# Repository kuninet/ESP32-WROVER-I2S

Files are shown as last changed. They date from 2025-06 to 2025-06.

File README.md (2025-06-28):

# ESP32-WROVER + I2S DACを使ったAirPlay、Bluetooth再生基板

## 概要

* ESP32-WROVER + I2S DACを使ったAirPlay、Bluetooth再生基板です。
* ファームウェアは、[squeezelite-esp32](https://github.com/sle118/squeezelite-esp32)を使用させていただきます。
  * https://github.com/sle118/squeezelite-esp32
* ファームウェアの書き込みには、ESP32 Downloader kitや、拙作[ESP32-Downloader](https://github.com/kuninet/ESP32-Downloader)をご使用ください。

## ☆現在 プリント基板を試作して確認中です。★

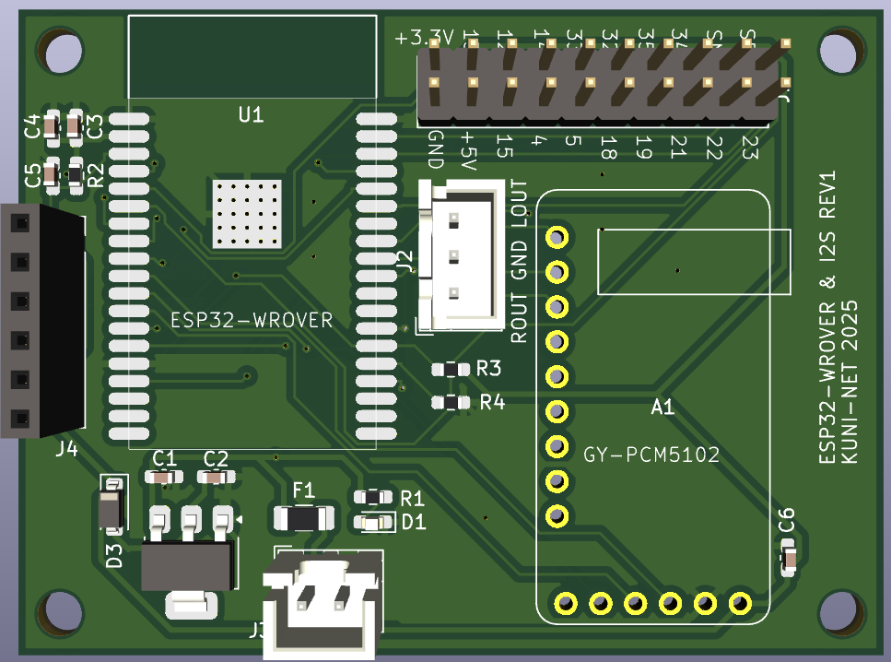
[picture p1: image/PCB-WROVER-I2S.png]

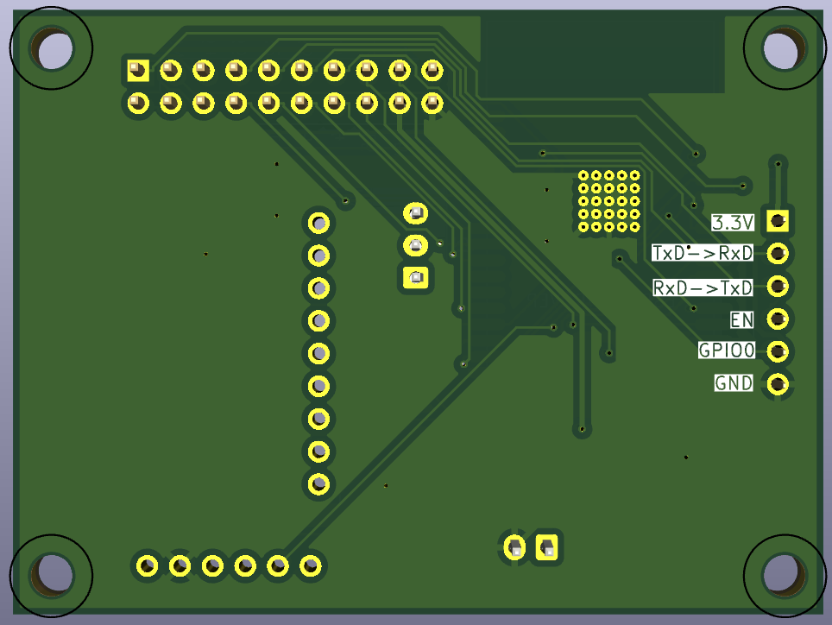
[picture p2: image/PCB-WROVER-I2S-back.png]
back-image


## 参考
* [ESP32でBluetooth／AirPlayスピーカーを作る](https://note.com/6ihwd/n/ncfccd1f401a1)
* [squeezelite-esp32](https://github.com/sle118/squeezelite-esp32)
* [zynthian-miniature](https://github.com/sstojos/zynthian-miniature)
* [KiCad Footprint and Component for ESP32-Wrover](https://github.com/aliafshar/esp32-wrover-kicad)

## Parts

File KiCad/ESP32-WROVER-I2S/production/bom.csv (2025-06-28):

Designator | Footprint | Quantity | Value | LCSC Part #
A1 | GY-PCM5102 | 1 | GY-PCM5102
C1, C2, C3 | 0603 | 3 | 22u
C4, C5, C6 | 0603 | 3 | 0.1u
D1 | 0603 | 1 | LED_POVER
D3 | D_SOD-123 | 1 | D_Schottky
F1 | 1206 | 1 | Polyfuse
J1 | PinHeader_2x10_P2.54mm_Vertical | 1 | Ext_con
J2 | JST_XH_B3B-XH-A_1x03_P2.50mm_Vertical | 1 | Audio_Con
J3 | JST_XH_B2B-XH-A_1x02_P2.50mm_Vertical | 1 | Power_Con
J4 | PinSocket_1x06_P2.54mm_Vertical | 1 | Downloader
R1 | 0603 | 1 | 2k
R2, R3 | 0603 | 2 | 10k
R4 | 0603 | 1 | 5.1k
U1 | ESP32-WROVER | 1 | ESP32-WROVER
U2 | SOT-223-3_TabPin2 | 1 | AMS1117-3.3

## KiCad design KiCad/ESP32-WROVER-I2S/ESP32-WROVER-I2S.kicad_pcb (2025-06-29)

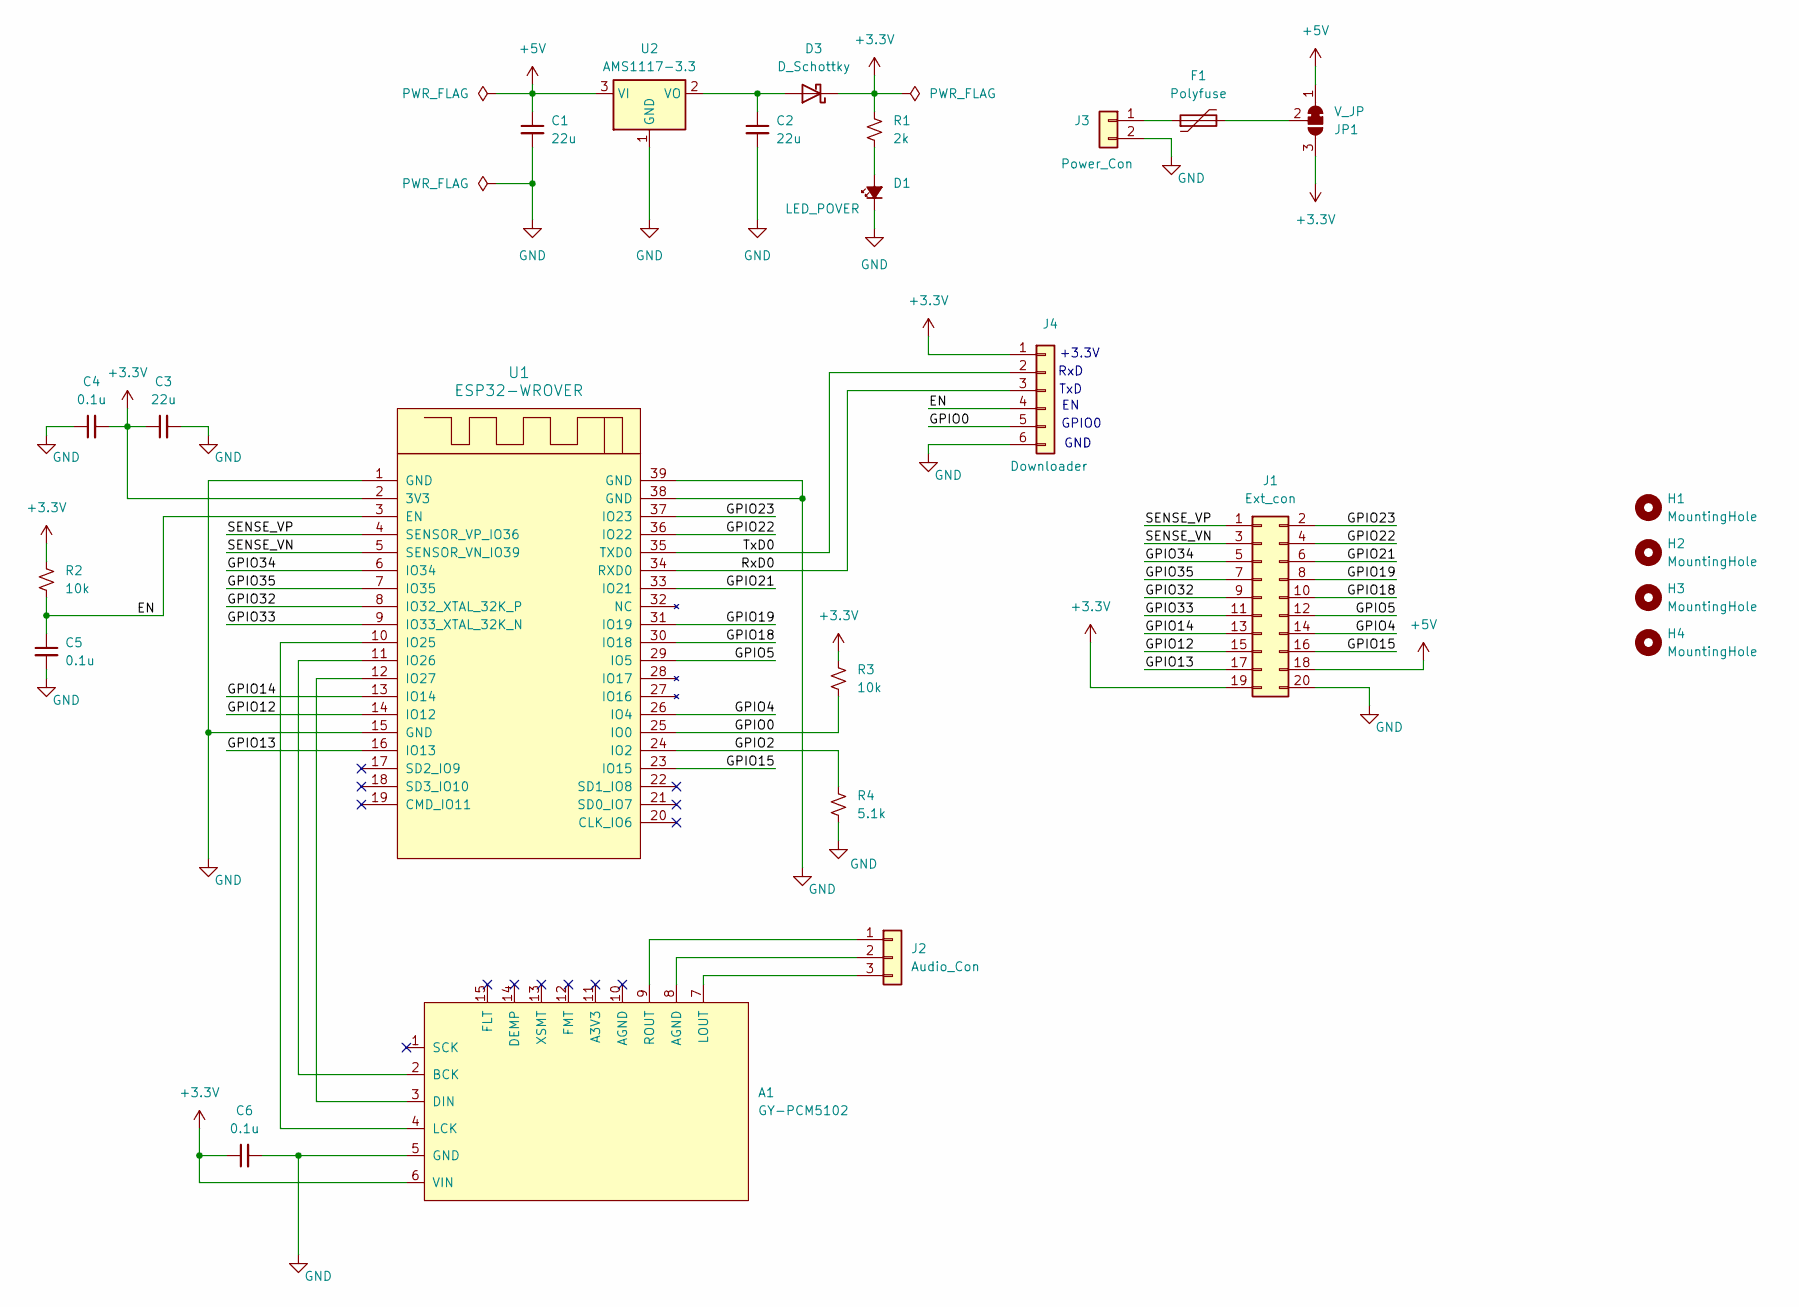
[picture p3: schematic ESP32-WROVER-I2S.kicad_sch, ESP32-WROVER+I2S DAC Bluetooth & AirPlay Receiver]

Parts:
A1: GY-PCM5102
C1, C2, C3: 22u; C_0603_1608Metric_Pad1.08x0.95mm_HandSolder
C4, C5, C6: 0.1u; C_0603_1608Metric_Pad1.08x0.95mm_HandSolder
D1: LED_POVER; LED_0603_1608Metric_Pad1.05x0.95mm_HandSolder
D3: D_Schottky; D_SOD-123
F1: Polyfuse; Fuse_1206_3216Metric_Pad1.42x1.75mm_HandSolder
H1, H2, H3, H4: MountingHole; MountingHole_3.2mm_M3
J1: Ext_con; PinHeader_2x10_P2.54mm_Vertical
J2: Audio_Con; JST_XH_B3B-XH-A_1x03_P2.50mm_Vertical
J3: Power_Con; JST_XH_B2B-XH-A_1x02_P2.50mm_Vertical
J4: Downloader; PinSocket_1x06_P2.54mm_Vertical
JP1: V_JP; SolderJumper-3_P1.3mm_Bridged12_Pad1.0x1.5mm_NumberLabels
R1: 2k; R_0603_1608Metric_Pad0.98x0.95mm_HandSolder
R2, R3: 10k; R_0603_1608Metric_Pad0.98x0.95mm_HandSolder
R4: 5.1k; R_0603_1608Metric_Pad0.98x0.95mm_HandSolder
U1: ESP32-WROVER
U2: AMS1117-3.3; SOT-223-3_TabPin2

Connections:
+3.3V: A1.6 (VIN), C3.1, C4.2, C6.1, D3.1 (K), J1.19, J4.1, JP1.3 (B), R1.1, R2.1, R3.1, U1.2 (3V3)
+5V: C1.1, J1.18, JP1.1 (A), U2.3 (VI)
/EN: C5.1, J4.4, R2.2, U1.3 (EN)
/GPIO0: J4.5, R3.2, U1.25 (IO0)
/GPIO2: R4.1, U1.24 (IO2)
/GPIO4: J1.14, U1.26 (IO4)
/GPIO5: J1.12, U1.29 (IO5)
/GPIO12: J1.15, U1.14 (IO12)
/GPIO13: J1.17, U1.16 (IO13)
/GPIO14: J1.13, U1.13 (IO14)
/GPIO15: J1.16, U1.23 (IO15)
/GPIO18: J1.10, U1.30 (IO18)
/GPIO19: J1.8, U1.31 (IO19)
/GPIO21: J1.6, U1.33 (IO21)
/GPIO22: J1.4, U1.36 (IO22)
/GPIO23: J1.2, U1.37 (IO23)
/GPIO32: J1.9, U1.8 (IO32_XTAL_32K_P)
/GPIO33: J1.11, U1.9 (IO33_XTAL_32K_N)
/GPIO34: J1.5, U1.6 (IO34)
/GPIO35: J1.7, U1.7 (IO35)
/RxD0: J4.3, U1.34 (RXD0)
/SENSE_VN: J1.3, U1.5 (SENSOR_VN_IO39)
/SENSE_VP: J1.1, U1.4 (SENSOR_VP_IO36)
/TxD0: J4.2, U1.35 (TXD0)
GND: A1.5 (GND), C1.2, C2.2, C3.2, C4.1, C5.2, C6.2, D1.1 (K), J1.20, J3.2, J4.6, R4.2, U1.1 (GND), U1.15 (GND), U1.38 (GND), U1.39 (GND), U2.1 (GND)
unnamed: A1.2 (BCK), U1.11 (IO26)
unnamed: A1.3 (DIN), U1.12 (IO27)
unnamed: A1.4 (LCK), U1.10 (IO25)
unnamed: A1.7 (LOUT), J2.3
unnamed: A1.9 (ROUT), J2.1
unnamed: D1.2 (A), R1.2
unnamed: C2.1, D3.2 (A), U2.2 (VO)
unnamed: A1.8 (AGND), J2.2
unnamed: F1.1, J3.1
unnamed: F1.2, JP1.2 (C)

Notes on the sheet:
GND
+3.3V
RxD
GPIO0
TxD

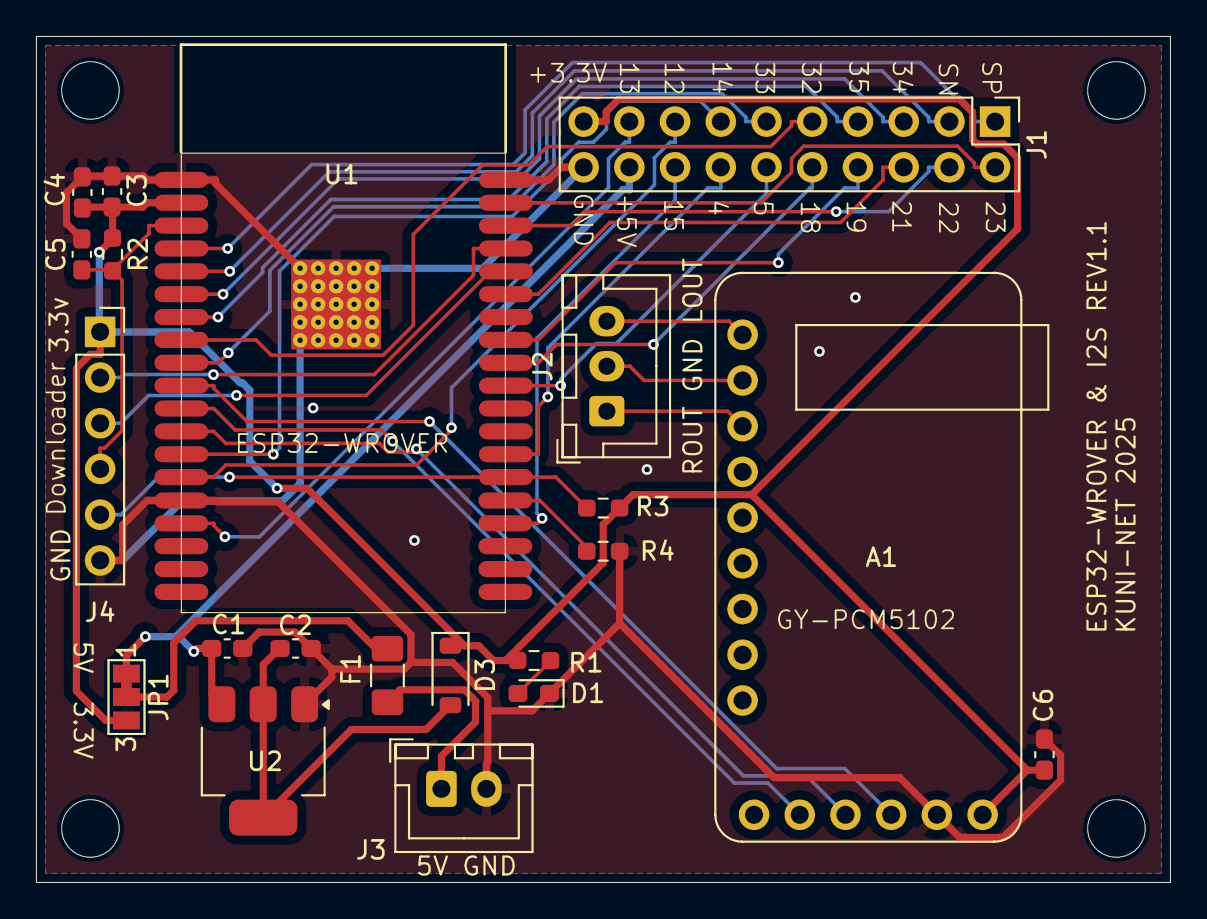
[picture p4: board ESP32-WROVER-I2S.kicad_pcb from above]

Board: 2 copper layers, 63.0 x 47.0 mm, 25 parts (0 on the bottom side), 35 nets.

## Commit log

2025-05-18 init commit
    [ESP32-WROVER-I2S.dsn, ESP32-WROVER-I2S.kicad_pcb, ESP32-WROVER-I2S.kicad_sch]
2025-05-18 README移動
2025-05-18 基板イメージ添付
2025-06-28 ガーバー出力
    [ESP32-WROVER-I2S.dsn, ESP32-WROVER-I2S.kicad_pcb, ESP32-WROVER-I2S.kicad_sch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]
2025-06-29 5v/3.3v切り替えジャンパ追加、電源LED変更、REV1.1ガーバー出力
    [ESP32-WROVER-I2S.dsn, ESP32-WROVER-I2S.kicad_pcb, ESP32-WROVER-I2S.kicad_sch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]
